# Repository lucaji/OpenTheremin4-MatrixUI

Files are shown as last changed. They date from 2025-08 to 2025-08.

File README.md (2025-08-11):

# OpenTheremin4+ Pitch Detection — Proof of Concept

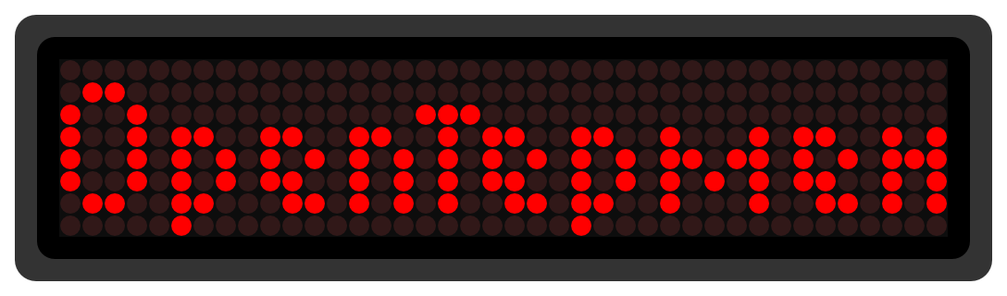
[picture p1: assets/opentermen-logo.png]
OpenTheremin Logo


> A modification and proof-of-concept project for the OpenTheremin V4 instrument, adding an LED matrix display for precise pitch and note indication.

## Quick Start

**What you need:**
- OpenTheremin V4.x board (assembled)
- Arduino UNO board
- HT1635A-based LED matrix board with 5× 8×8 modules
- Dupont wires (for serial TX/RX and I2C)
- PlatformIO installed in VS Code

**Wiring overview:**
1. **OpenTheremin → Arduino UNO**  
   - TX ↔ RX (cross-connect)  
   - GND ↔ GND  
   - On V4.0: solder RX to U10 pin 2 (CH340G)  
   - On V4.5: use pads J3 for both TX and RX
2. **Arduino UNO → HT1635A display board**  
   - I²C (SDA/SCL) + 5V + GND

**To run:**
1. Clone this repository
2. In PlatformIO:
   - Open the `display_firmware` project → select UNO COM port → Upload
   - Open the `opentheremin_mod_firmware` project → select Theremin COM port → Upload
3. Power both boards via USB (or a shared supply)  
4. The LED display will now show the current pitch in real time.

Please refer to the included block diagram below.

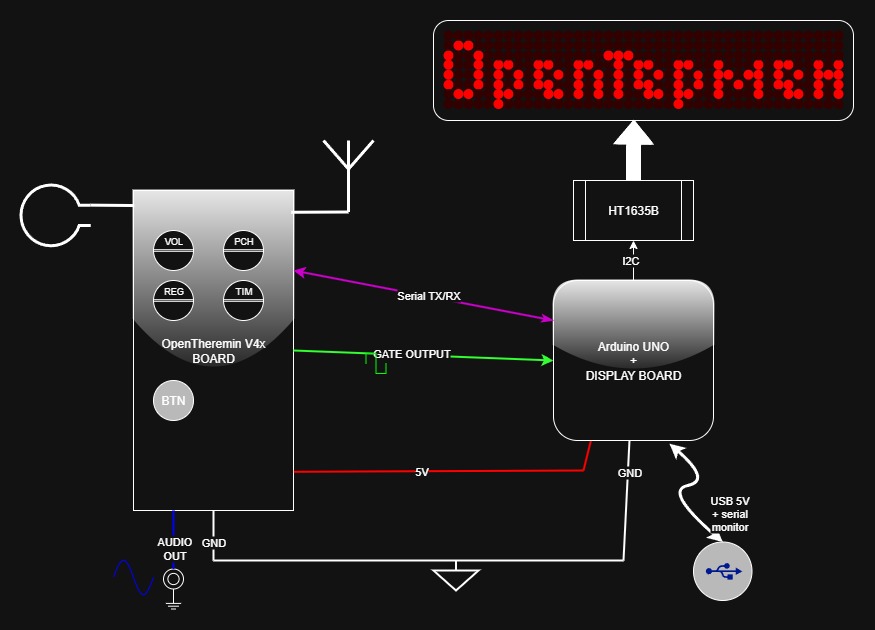
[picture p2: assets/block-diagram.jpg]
Block Diagram


- Both boards communicate via **cross-connected serial ports** (TX↔RX).
- **OpenTheremin V4.0:** TX pad available, RX requires soldering to U10 pin 2 (CH340G).  
- **OpenTheremin V4.5:** Both TX and RX available at solder pads J3.

## Menu & UI Functionality

The user interface is minimal, operated via the **single capacitive touch button** on the OpenTheremin board.

> The menu system cycles through modes and options with **short taps** and confirms selections with **long presses**.

**Main features:**

1. **Calibration**
   - After the first long press, the display will show `CAL?` and with a second long-press you will initiate the calibration procedure on the Theremin.
   When confirming the calibration, the color LEDs will blink briefly signalling to stand in front of the theremin at a comfortable distance and with your hands **away** from the antennas.
   After the calibration is finished, a brief `CALOK` message will put you back into performance mode, otherwise a `CALER` will offer you another attempt.

1. **Layout Selection**  
   - `NUM` **Numeric deviation**: Shows note + octave + cent deviation numerically  
   - `BAR` **Bar graph**: Visual representation of pitch drift from the target note  
   - `PNO` **Piano keyboard**: Highlights current note position on an octave graphic

2. **Concert A Reference**  
   - Preset options: `440 Hz` `445 Hz` `430 Hz` and `432 Hz`
   - Long-press to confirm and store selection

3. **Notation System** (future expansion)  
   - Current: English sharp notation (C, C#, D...)  
   - Planned: Flats, Solfège, and German notation

**Navigation Logic:**
- **Short tap** → Next menu item or value  
- **Long press** → Confirm selection / return to main display  
- In **main tuner view mode**, short taps cycle between `MUTED` and `PLAY!` to control the audio output directly.

---

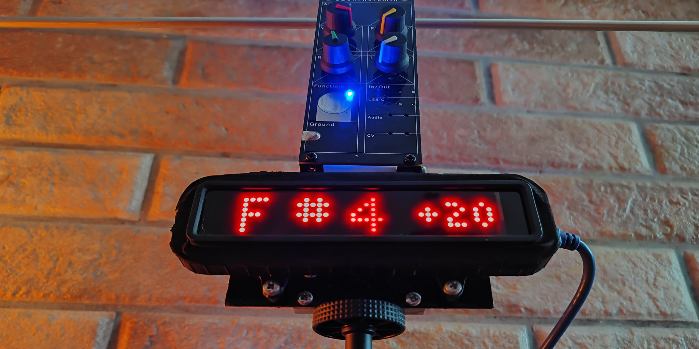
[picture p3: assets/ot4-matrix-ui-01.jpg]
LED Matrix UI


**OpenTheremin with LED matrix display for real-time pitch indication using an HT1635A driver and five 8×8 LED modules.**

## Overview

This project is a **proof-of-concept (POC)** for two main reasons:

1. **Non-optimal display hardware**  
   The LED matrix display board used here was a scrap leftover with less-than-ideal wiring (row/column swapping, reversed bit order).  
   Although a schematic is provided, a redesigned PCB would simplify addressing and improve performance.

2. **Original MCU limitations**  
   The ATmega328p on the OpenTheremin V4 is already at full capacity running the DDS generator and near real-time digital heterodyne system.  
   A second Arduino UNO is therefore required for pitch detection and display driving via the HT1635A.

Communication between the two boards is handled exclusively via the serial port, avoiding any additional load on the main Theremin processor and ensuring glitch-free performance.

## Pitch Indication

The detection system displays:

- **Pitch note** (C, D, E… with sharps/flats)  
- **Octave number**  
- **Deviation in cents** from equal temperament

The display firmware supports **three layouts**:

1. **Numeric deviation**

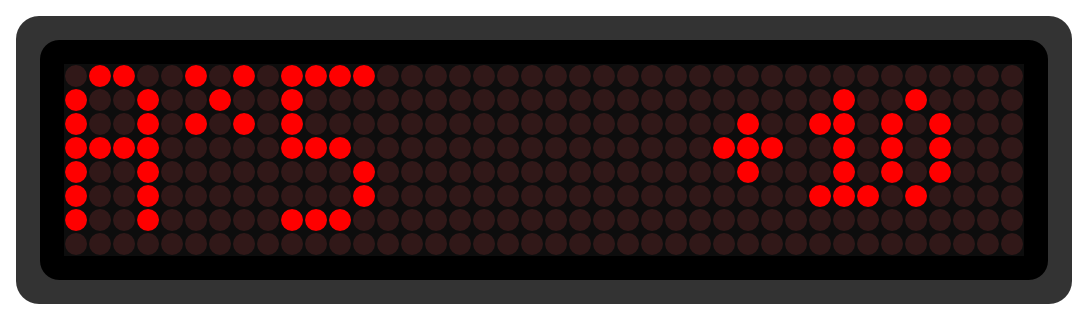
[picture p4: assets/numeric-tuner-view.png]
Numeric Tuner View


2. **Bar graph**

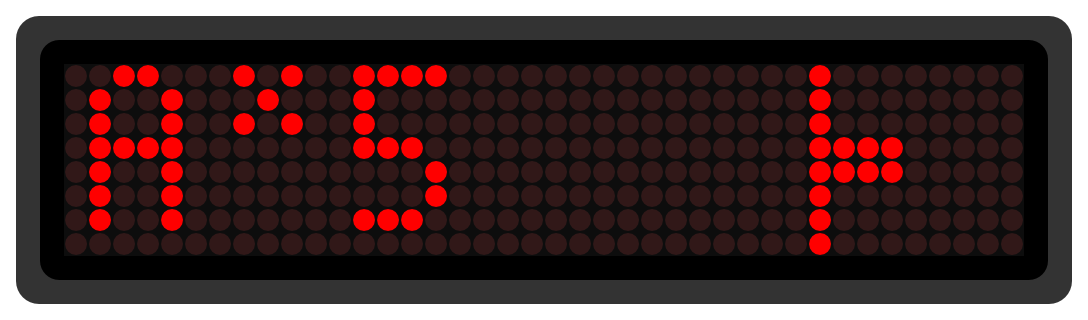
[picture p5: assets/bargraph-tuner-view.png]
Bar-graph Tuner View


3. **Piano keyboard**

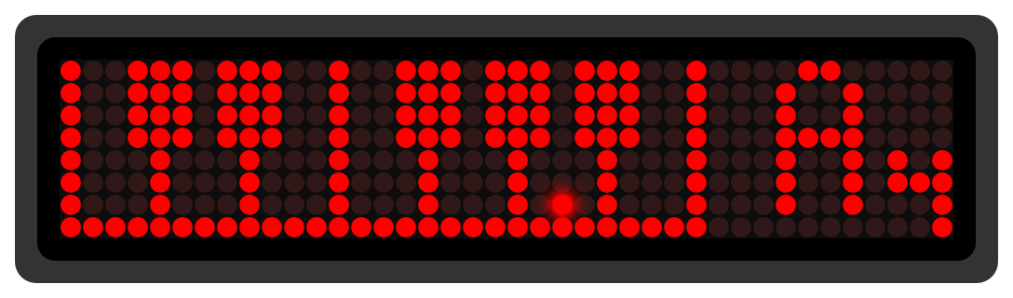
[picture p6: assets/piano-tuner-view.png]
Piano Tuner View


Because of the limited matrix resolution, each layout is a trade-off between visual appeal and precision.

The firmware allows selection of **Concert A tuning** (440 Hz, 432 Hz, etc.) and basic configuration using a **single touch button**.

---

### HT1635A Display Driver

- Controls five 8×8 LED matrices
- Displays standard note names with accidentals
- Shows cent deviation in a smaller font
- Aids Theremin learning by providing visual pitch feedback without the need for another tuned reference instrument (unless you have perfect pitch).

---

### Modded Theremin Firmware

The modified OpenTheremin V4 firmware enables the **GATE output** (ring contact of the audio jack) to emit a square wave pulse at the DDS output frequency.  
This signal is:

- Measured by the secondary Arduino UNO  
- Independent of the volume antenna position  
- Active even when the Theremin is muted

## Hardware Requirements

- **OpenTheremin V4.x** (assembled)  
- **Arduino UNO** as display controller  
- HT1635A-based LED matrix board (five 8×8 modules)  
- I²C connection between UNO and display

Using a second MCU is the simplest way to handle the display without interfering with the Theremin's strict timing requirements or consuming its limited program space.

---

### Display Board Notes

The provided schematic (KiCad v9) reflects a **non-ideal wiring** where row and column lines are swapped and interlaced between display modules.

The HT1635’s RAM is divided into 4-bit nibbles within 40 bytes, requiring careful addressing. Refer to the attached datasheet file for more information.

## Development Environment

This project uses **PlatformIO** for a better workflow than Arduino IDE.  
[Install PlatformIO for VS Code](https://platformio.org/install/ide?install=vscode).

The repo contains **two separate firmware projects**:

1. Modified OpenTheremin firmware  
2. Display board firmware

---

### Serial Port Selection

When uploading:

- Select the correct COM port in each project’s `platformio.ini` (`upload_port = COMx`)
- The OpenTheremin board usually appears as **USB-SERIAL CH340**  
- The Arduino UNO appears as **Arduino UNO**

Keeping both boards connected via USB allows simultaneous UART logging during development.

## Roadmap

- Redesign HT1635 PCB for logical row/column mapping
- Add variable-width font support (currently fixed 6×5)
- Implement additional pitch notation systems:  
   - English sharp/flat  
   - Solfège (Do/Re/Mi) sharp/flat  
   - German sharp/flat

## About the Theremin
The Theremin, invented by Leon Theremin in 1920, is played without physical contact:
One hand controls pitch, the other volume, by moving in proximity to two antennas.

The startup logo in this project merges “Open” with Lev Sergeevič Termen’s surname in Cyrillic (Термен) to fit perfectly on the 8×8×5 matrix display.

## Credits

- Urs Gaudenz (gaudi.ch) — OpenTheremin boards and project founder

- All contributors to the OpenTheremin project

- draw.io Desktop — used for the block diagram

## Revision History

- August 2025 — Initial release by Luca Cipressi [(lucaji.github.io)](http://lucaji.github.io)

## License

Display firmware is licensed under GNU GPL v3.

(c) 2025 Luca Cipressi [(lucaji.github.io)](http://lucaji.github.io)

The original Theremin firmware retains its respective copyrights.

See the full license text in the repository.

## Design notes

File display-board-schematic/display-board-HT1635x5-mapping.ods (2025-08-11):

 | data byte |  |  |  |  |  |  |  |  |  | data byte |  |  |  |  |  |  |  |  |  | data byte |  |  |  |  |  |  |  |  |  | data byte |  |  |  |  |  |  |  |  |  | data byte |  |  |  |  |  |  |  |  |  | data byte
 | 7 | 6 | 5 | 4 | 3 | 2 | 1 | 0 |  |  | 7 | 6 | 5 | 4 | 3 | 2 | 1 | 0 |  |  | 7 | 6 | 5 | 4 | 3 | 2 | 1 | 0 |  |  | 7 | 6 | 5 | 4 | 3 | 2 | 1 | 0 |  |  | 7 | 6 | 5 | 4 | 3 | 2 | 1 | 0 |  |  | 7 | 6 | 5 | 4 | 3 | 2 | 1 | 0
Row # |  |  |  |  |  |  |  |  | ADDR | Row# |  |  |  |  |  |  |  |  | ADDR | Row# |  |  |  |  |  |  |  |  | ADDR | Row# |  |  |  |  |  |  |  |  | ADDR | Row# |  |  |  |  |  |  |  |  | ADDR | Row#
0x00 |  |  |  |  |  |  |  |  | 0x00 | 0x08 |  |  |  |  |  |  |  |  | 0x10 | 0x10 |  |  |  |  |  |  |  |  | 0x20 | 0x18 |  |  |  |  |  |  |  |  | 0x30 | 0x20 |  |  |  |  |  |  |  |  | 0x40 | 0x28 | NC | NC | NC | NC | NC | NC | NC | NC
0x01 |  |  |  |  |  |  |  |  | 0x02 | 0x09 |  |  |  |  |  |  |  |  | 0x12 | 0x11 |  |  |  |  |  |  |  |  | 0x22 | 0x19 |  |  |  |  |  |  |  |  | 0x32 | 0x21 |  |  |  |  |  |  |  |  | 0x42 | 0x29 | NC | NC | NC | NC | NC | NC | NC | NC
0x02 |  |  |  |  |  |  |  |  | 0x04 | 0x0A |  |  |  |  |  |  |  |  | 0x14 | 0x12 |  |  |  |  |  |  |  |  | 0x24 | 0x1A |  |  |  |  |  |  |  |  | 0x34 | 0x22 |  |  |  |  |  |  |  |  | 0x44 | 0x2A | NC | NC | NC | NC | NC | NC | NC | NC
0x03 |  |  |  |  |  |  |  |  | 0x06 | 0x0B |  |  |  |  |  |  |  |  | 0x16 | 0x13 |  |  |  |  |  |  |  |  | 0x26 | 0x1B |  |  |  |  |  |  |  |  | 0x36 | 0x23 |  |  |  |  |  |  |  |  | 0x46 | 0x2B | NC | NC | NC | NC | NC | NC | NC | NC
0x04 |  |  |  |  |  |  |  |  | 0x08 | 0x0C |  |  |  |  |  |  |  |  | 0x18 | 0x14 |  |  |  |  |  |  |  |  | 0x28 | 0x1C |  |  |  |  |  |  |  |  | 0x38 | 0x24 |  |  |  |  |  |  |  |  | 0x48
0x05 |  |  |  |  |  |  |  |  | 0x0A | 0x0D |  |  |  |  |  |  |  |  | 0x1A | 0x15 |  |  |  |  |  |  |  |  | 0x2A | 0x1D |  |  |  |  |  |  |  |  | 0x3A | 0x25 |  |  |  |  |  |  |  |  | 0x4A
0x06 |  |  |  |  |  |  |  |  | 0x0C | 0x0E |  |  |  |  |  |  |  |  | 0x1C | 0x16 |  |  |  |  |  |  |  |  | 0x2C | 0x1E |  |  |  |  |  |  |  |  | 0x3C | 0x26 |  |  |  |  |  |  |  |  | 0x4C
0x07 |  |  |  |  |  |  |  |  | 0x0E | 0x0F |  |  |  |  |  |  |  |  | 0x1E | 0x17 |  |  |  |  |  |  |  |  | 0x2E | 0x1F |  |  |  |  |  |  |  |  | 0x3E | 0x27 |  |  |  |  |  |  |  |  | 0x4E
 | MSB |  |  |  | LSB |  |  |  |  |  | MSB |  |  |  | LSB |  |  |  |  |  | MSB |  |  |  | LSB |  |  |  |  |  | MSB |  |  |  | LSB |  |  |  |  |  | MSB |  |  |  | LSB |  |  |  |  |  | MSB |  |  |  | LSB
 |  | C |  |  |  | D |  |  |  |  |  | E |  |  |  | F |  |  |  |  |  | G |  |  |  | A |  |  |  |  |  | B
drift col: | 0 | 1 | 2 | 3 | 4 | 5 | 6 | 7 |  |  | 8 | 9 | 10 | 11 | 12 | 13 | 14 | 15 |  |  | 16 | 17 | 18 | 19 | 20 | 21 | 22 | 23 |  |  | 24 | 25 | 26 | 27 | 28
 |  |  |  | C# Db |  |  |  |  |  |  |  |  |  |  |  |  |  |  |  |  |  |  |  | G# Ab
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

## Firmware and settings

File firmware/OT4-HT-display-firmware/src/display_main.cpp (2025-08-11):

/**
 * @file display_main.cpp
 * @brief UI state machine for the display board connected to OpenTheremin over UART.
 *
 * Responsibilities:
 *  - Render tuner views (numeric / bar / keyboard).
 *  - Handle single-button UX via short/long presses forwarded from the Theremin board.
 *  - Drive a small configuration menu (calibration, view mode, Concert A reference).
 *  - Show transient feedback for Register (octave) and Timbre (wavetable) changes.
 */
#include "display_main.h"
#include "../../build_options.h"
#include "HT1635.h"
#include "freq.h"
#include "../../eeprom.h"


// ==== Configuration & constants =================================================

/** EEPROM addresses (byte indices). */
static constexpr uint16_t EEPROM_TUNER_VIEW_MODE_ADDRESS = 0x00;
static constexpr uint16_t EEPROM_CONCERT_REF_A_ADDRESS   = 0x01;

/** UI timing (ms). */
static constexpr uint32_t UI_UPDATE_DELAY_MS = 100;
static constexpr uint32_t UI_TEMPORARY_PARAMETER_DISPLAY_MS = 1800;

/** Concert A bounds (Hz) for validation. */
static constexpr float CONCERT_A_MIN = 300.0f;
static constexpr float CONCERT_A_MAX = 600.0f;
static constexpr float CONCERT_A_DEFAULT = 440.0f;

/** Minimum frequency to consider “valid” for note rendering. */
static constexpr float MIN_VALID_FREQ = 10.0f;

// ==== Types =====================================================================

/**
 * @brief UI "page" / status machine for the display.
 */
typedef enum : uint8_t {
    tuner_view = 0,                 /**< Main tuner page. */

    // Menu items (cycled by short presses, confirmed by long press)
    menu_item_cal_enter,
    menu_item_pitch_display_mode_numeric,
    menu_item_pitch_display_mode_bar,
    menu_item_pitch_display_mode_keyboard,
    menu_item_concert_a_440,
    menu_item_concert_a_445,
    menu_item_concert_a_430,
    menu_item_concert_a_432,

    // Temporary feedback display (auto-exit)
    parameter_change_view_temporary_enter,
    parameter_change_view_temporary_wait,

} theremin_status_display_t;

/**
 * @brief What kind of temporary parameter feedback is being shown.
 */
typedef enum : uint8_t {
    none = 0,
    octave,     /**< Register change feedback. */
    timbre,     /**< Waveform change feedback. */
    status_msg, /**< Short textual status like PLAY!/MUTED/etc. */
    menu_txt    /**< Menu text; persists until user action. */
} display_status_parameter_t;

// ==== Globals (module-local) =====================================================

static HT1635 ht_display;

static theremin_state_t _theremin_state = muted;
static theremin_status_display_t _display_status = tuner_view;
static display_status_parameter_t _parameter_display_status = none;

static uint8_t _parameter_value = 0;
static float _concert_reference_a = CONCERT_A_DEFAULT;

// ==== Accessors =================================================================

theremin_state_t get_theremin_state() { return _theremin_state; }


/** Clear screen and return to the main tuner view. */
void restore_tuner_view() {
    _display_status = tuner_view;
    ht_display.update_display();
}


void display_ui_init() {
    ht_display.display_startup_logo();
    ht_display.update_display();
}

/**
 * @brief Show a short message and (optionally) mark it as a temporary parameter display.
 * @param kind One of @ref display_status_parameter_t.
 * @param txt  Null-terminated 5-char string for the 5-char area.
 */
static void display_status_msg(display_status_parameter_t kind, const char* txt) {
    _parameter_display_status = kind;
    // For menu text we keep the current page; for others we enter temporary view.
    if (kind != menu_txt) {
        _display_status = parameter_change_view_temporary_enter;
    }
    ht_display.print_string5(txt);
}

/** Draw menu page by enum. */
void display_menu(theremin_status_display_t status) {
    _display_status = status;
    HT1635::tuner_view_mode_t tuner_view_mode = ht_display.get_tuner_view_mode();
    switch (status) {
        case menu_item_cal_enter: display_status_msg(menu_txt, "CAL? "); break;
        
        case menu_item_pitch_display_mode_numeric:
            if (tuner_view_mode == HT1635::tuner_view_mode_t::numeric) {
                display_status_msg(menu_txt, "NUM <");
            } else {
                display_status_msg(menu_txt, "NUM? ");
            }
            break;
        case menu_item_pitch_display_mode_bar:
            if (tuner_view_mode == HT1635::tuner_view_mode_t::bar_graph) {
                display_status_msg(menu_txt, "BAR <");
            } else {
                display_status_msg(menu_txt, "BAR? ");
            }
            break;
        case menu_item_pitch_display_mode_keyboard:
            if (tuner_view_mode == HT1635::tuner_view_mode_t::piano_view) {
                display_status_msg(menu_txt, "PNO <");
            } else {
                display_status_msg(menu_txt, "PNO? ");
            }
            break;
        
        case menu_item_concert_a_440:
            if (fabsf(_concert_reference_a - 440.0f) < 0.01f) {
                display_status_msg(menu_txt, "A440<");
            } else {
                display_status_msg(menu_txt, "A440?");
            }
            break;
        case menu_item_concert_a_445:
            if (fabsf(_concert_reference_a - 445.0f) < 0.01f) {
                display_status_msg(menu_txt, "A445<");
            } else {
                display_status_msg(menu_txt, "A445?");
            }
            break;
        case menu_item_concert_a_430:
            if (fabsf(_concert_reference_a - 430.0f) < 0.01f) {
                display_status_msg(menu_txt, "A430<");
            } else {
                display_status_msg(menu_txt, "A430?");
            }
            break;
        case menu_item_concert_a_432:
            if (fabsf(_concert_reference_a - 432.0f) < 0.01f) {
                display_status_msg(menu_txt, "A432<");
            } else {
                display_status_msg(menu_txt, "A432?");
            }
            break;

        default: 
        break;
    }
}

/**
 * @brief Handle a user action forwarded from the Theremin (short/long press).
 * Short press: step or toggle; Long press: confirm/apply for the current menu item.
 * @param shortPress true for short press, false for long press.
 */
void handle_user_action(bool shortPress) {
    HT1635::tuner_view_mode_t tuner_view_mode = ht_display.get_tuner_view_mode();
    bool shall_restore_tuner_view = false;
    switch (_display_status) {
        case tuner_view:
            if (shortPress) {
                if (_theremin_state == muted) {
                    Serial.write(STATE_CMD_UNMUTE);
                } else if (_theremin_state == playing) {
                    Serial.write(STATE_CMD_MUTE);
                }
            } else {
                display_menu(menu_item_cal_enter);
            }
        break;

        case menu_item_cal_enter:
            if (shortPress) {
                display_menu(menu_item_pitch_display_mode_numeric);
            } else {
                Serial.write(STATE_CMD_CALIBRATION);
            }
            break;

        case menu_item_pitch_display_mode_numeric:
            if (shortPress) {
                display_menu(menu_item_pitch_display_mode_bar);
            } else {
                tuner_view_mode = ht_display.set_tuner_view_mode(HT1635::tuner_view_mode_t::numeric);
                EEPROM.put(EEPROM_TUNER_VIEW_MODE_ADDRESS, tuner_view_mode);
                shall_restore_tuner_view = true;
            }
            break;

        case menu_item_pitch_display_mode_bar:
            if (shortPress) {
                display_menu(menu_item_pitch_display_mode_keyboard);
            } else {
                tuner_view_mode = ht_display.set_tuner_view_mode(HT1635::tuner_view_mode_t::bar_graph);
                EEPROM.put(EEPROM_TUNER_VIEW_MODE_ADDRESS, tuner_view_mode);
                shall_restore_tuner_view = true;
            }
            break;

        case menu_item_pitch_display_mode_keyboard:
            if (shortPress) {
                display_menu(menu_item_concert_a_440);
            } else {
                tuner_view_mode = ht_display.set_tuner_view_mode(HT1635::tuner_view_mode_t::piano_view);
                EEPROM.put(EEPROM_TUNER_VIEW_MODE_ADDRESS, tuner_view_mode);
                shall_restore_tuner_view = true;
            }
            break;

        case menu_item_concert_a_440:
            if (shortPress) {
                display_menu(menu_item_concert_a_445);
            } else {
                _concert_reference_a = 440.0f;
                EEPROM.put(EEPROM_CONCERT_REF_A_ADDRESS, _concert_reference_a); 
                shall_restore_tuner_view = true;
            }
            break;

        case menu_item_concert_a_445:
            if (shortPress) {
                display_menu(menu_item_concert_a_430);
            } else {
                _concert_reference_a = 445.0f;
                EEPROM.put(EEPROM_CONCERT_REF_A_ADDRESS, _concert_reference_a); 
                shall_restore_tuner_view = true;
            }
            break;

        case menu_item_concert_a_430:
            if (shortPress) {
                display_menu(menu_item_concert_a_432);
            } else {
                _concert_reference_a = 430.0f;
                EEPROM.put(EEPROM_CONCERT_REF_A_ADDRESS, _concert_reference_a); 
                shall_restore_tuner_view = true;
            }
            break;

        case menu_item_concert_a_432:
            if (shortPress) {
                shall_restore_tuner_view = true;
            } else {
                _concert_reference_a = 432.0f;
                EEPROM.put(EEPROM_CONCERT_REF_A_ADDRESS, _concert_reference_a); 
                shall_restore_tuner_view = true;
            }
            break;

        default: break;
    }
    if (shall_restore_tuner_view) {
        restore_tuner_view();
    }
}


/**
 * @brief Read persistent settings from EEPROM and validate.
 */
static void settings_read() {
    // View mode
    int8_t tvm = 0;
    EEPROM.get(EEPROM_TUNER_VIEW_MODE_ADDRESS, tvm);
    if (tvm < 0 || tvm >= HT1635::tuner_view_mode_t::tuner_view_mode_t_last) {
        tvm = HT1635::tuner_view_mode_t::piano_view;
    }
    HT1635::tuner_view_mode_t tuner_view_mode = static_cast<HT1635::tuner_view_mode_t>(tvm);
    ht_display.set_tuner_view_mode(tuner_view_mode);

    float ref_a = 0.0f;
    EEPROM.get(EEPROM_CONCERT_REF_A_ADDRESS, ref_a);
    if (ref_a < CONCERT_A_MIN || ref_a > CONCERT_A_MAX) {
        ref_a = CONCERT_A_DEFAULT;
    }
    _concert_reference_a = ref_a;
}

/**
 * @brief Initialize the HT1635 display and show startup screen.
 */
void setup() {
    Serial.begin(SERIAL_SPEED);
    settings_read();
    ht_display.begin();
    display_ui_init();
    freq_init();
    DEBUG_PRINTLN(F("Display UI ready."));
    _display_status = tuner_view;
}

// ==== Arduino lifecycle ==========================================================

void loop() {
    static unsigned long tuner_view_update_old_tick = 0;
    static unsigned long parameter_view_update_old_tick = 0;

    float raw = freq_read();
    unsigned long t = millis();
    
    // ---- UART protocol from Theremin ------------------------------------------
    if (Serial.available()) {
        uint8_t b = Serial.read();
        switch (b) {
            case STATE_CMD_MUTE:
                _theremin_state = muted;
                display_status_msg(status_msg, "MUTED");
                break;

            case STATE_CMD_UNMUTE:
                _theremin_state = playing;
                display_status_msg(status_msg, "PLAY!");
                break;

            case STATE_CMD_CALIBRATION:
                _theremin_state = calibrating;
                display_status_msg(status_msg, "-CAL-");
                ht_display.set_blink_mode(HT1635::blink_setting_t::BLINK_1Hz);
                break;

            case STATE_CMD_CALIBRATION_SUCCESS:
                _theremin_state = playing;
                ht_display.set_blink_mode(HT1635::blink_setting_t::BLINK_OFF);
                display_status_msg(status_msg, "CALOK");
                break;

            case STATE_CMD_CALIBRATION_ERROR:
                _theremin_state = muted;
                ht_display.set_blink_mode(HT1635::blink_setting_t::BLINK_OFF);
                display_status_msg(status_msg, "CALER");
                _display_status = menu_item_cal_enter;
                break;

            case STATE_CMD_BUTTON_SHORT_PRESS:
                handle_user_action(true);
                break;

            case STATE_CMD_BUTTON_LONG_PRESS:
                handle_user_action(false);
                break;

            default:
                // Parameter ranges: Register (octave) and Timbre (wavetable index).
                if (b >= STATE_CMD_REGISTER_LOW && b <= STATE_CMD_REGISTER_HIGH) {
                    _display_status = parameter_change_view_temporary_enter;
                    _parameter_display_status = octave;
                    _parameter_value = b;
                } else if (b >= STATE_CMD_WAVEFORM_BASE && b <= (STATE_CMD_WAVEFORM_BASE + 0x9)) {
                    _display_status = parameter_change_view_temporary_enter;
                    _parameter_display_status = timbre;
                    _parameter_value = b - STATE_CMD_WAVEFORM_BASE;
                } else {
                    // Unrecognized; ignore or DEBUG_PRINT(b);
                    //DEBUG_PRINT(b); // echo
                }
                break;
        }
    }

    switch (_display_status) {
        case tuner_view:
            if (t - tuner_view_update_old_tick > UI_UPDATE_DELAY_MS) {
                tuner_view_update_old_tick = t;
                ht_display.render_pitch_and_drift(raw, _concert_reference_a, MIN_VALID_FREQ);
            }
            break;

        case parameter_change_view_temporary_enter:
            parameter_view_update_old_tick = t;
            switch (_parameter_display_status) {
                case octave: {
                    char txt[6] = "OCT+1";
                    if (_parameter_value == STATE_CMD_REGISTER_LOW) {
                        txt[3] = '-';
                    } else if (_parameter_value == STATE_CMD_REGISTER_MID) {
                        txt[4] = '0';
                    } 
                    ht_display.print_string5(txt);
                } break;

                case timbre: {
                    char txt[6] = "WAV  ";
                    txt[4] = char((_parameter_value % 10) + '0');
                    ht_display.print_string5(txt);
                } break;

                default: break;
            }
            _display_status = parameter_change_view_temporary_wait;
            break;

        case parameter_change_view_temporary_wait:
            if (_parameter_display_status == menu_txt || _theremin_state == calibrating) {
                // menu items stays until user exits menu.
                // calibration stays until success or failure.
            } else if (t - parameter_view_update_old_tick > UI_TEMPORARY_PARAMETER_DISPLAY_MS) {
                _display_status = tuner_view;
                _parameter_display_status = none;
                restore_tuner_view();
            }

            break;

        default: break;
    }
        

        


}

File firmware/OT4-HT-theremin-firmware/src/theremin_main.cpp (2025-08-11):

#include <Arduino.h>
#include "../../build_options.h"
#include "dac.h"
#include "ihandlers.h"
#include "timer.h"
#include "eeprom.h"
#include "hw.h"
#include "ui.h"
#include "calibration.h"
#include "cv.h"

void setup() {
    Serial.begin(SERIAL_SPEED);

    pinMode(BUTTON_PIN, INPUT_PULLUP);
    pinMode(LED_BLUE_PIN, OUTPUT);
    pinMode(LED_RED_PIN, OUTPUT);
    pinMode(GATE_PIN, OUTPUT);

    ui_initialize();

    calibration_read();
    ihInitialiseTimer();
    ihInitialiseInterrupts();

    DEBUG_PRINTLN("Hello, Theremin world!");
}

void loop() {
    int32_t pitch_v = 0;    // averaged pitch counter value
    int32_t pitch_l = 0;    // stored pitch counter value
    
    int32_t vol_v = 0;      // averaged volume counter value
    int32_t vol_l = 0;      // stored volume counter value

    int32_t clampedVol;     // clamped volume amplitude
    int32_t clampedPitch;   // clamped pitch for phase accumulator

mloop: // Main loop avoiding the GCC "optimization"

    if (pitchValueAvailable) {
        // --- Smooth pitch value (simple IIR low-pass filter) ---
        pitch_v = pitch_l + ((pitch - pitch_l) >> 2); // (low-pass) exponential moving average (EMA) approximation 75% previous, 25% new
        pitch_l = pitch_v;
        /*
        ((int32_t)pitchPotValue << 1)   // for half sensitivity
        ((int32_t)pitchPotValue << 3)   // for double sensitivity
        ((int32_t)pitchPotValue - 512) << 2   // center the pot at zero offset
        */
        #if PITCH_FIELD_MODE == PITCH_FIELD_MODE_SYMMETRICAL
            int32_t virtualPitch = pitch_v + (((int32_t)pitchPotValue - 512) << 2);  // apply offset
            clampedPitch = abs(pitchCalibrationBase - virtualPitch);
        #else
            clampedPitch = (pitchCalibrationBase - pitch_v) + 2048 - (pitchPotValue << 2);
        #endif
        if (clampedPitch < 0) { 
            // Lower clamp
            clampedPitch = 0;
        } else if (clampedPitch > 16383) {
            // Upper clamp
            // 16383 = 2^14 - 1
            // This value is shifted right by registerValue, or the selected octave (or pitch register).
            // If registerValue == 0, no shift: vPointerIncrement = 16383 (maximum playback speed).
            // vPointerIncrement is directly used to advance the phase pointer per sample.
            // Larger values -> faster wavetable traversal -> higher pitch.
            // Using a limit of 16383 ensures that:
            // - The shifted result stays within a reasonable frequency range, avoiding unplayably high tones.
            // - avoid wraparound in the phase accumulator or numeric overflow in later math.
            // - It fits well with common 10.6 fixed-point formats.
            clampedPitch = 16383;
        }
        setWavetableSampleAdvance((uint16_t)clampedPitch >> registerValue);
        
        #if CV_OUTPUT_MODE != CV_OUTPUT_MODE_OFF
            if (clampedPitch != pitch_p) { 
                // output new pitch CV value only if pitch value changed (saves runtime resources)
                pitch_p = clampedPitch;
                #if CV_OUTPUT_MODE == CV_OUTPUT_MODE_LOG
                    log_freq = log2U16((uint16_t)clampedPitch);
                    if (log_freq >= 37104) {
                        // 37104 = log2U16(512) + 48*4096/819
                        pitchCV = (int16_t)((819 * (log_freq - 37104)) >> 12);
                        pitchCV >>= registerValue - 1;
                    } else {
                        pitchCV = 0;
                    }
                #elif CV_OUTPUT_MODE == CV_OUTPUT_MODE_LINEAR
                    // 819Hz/V for Korg & Yamaha
                    pitchCV = clampedPitch >> 2 >> (registerValue - 1);
                #endif
                pitchCVAvailable = true;
            }
        #endif
        pitchValueAvailable = false;  // consume the flag
    }

    if (volumeValueAvailable) {
        // Average and clamp volume values
        vol = max(vol, 5000);
        vol_v = vol_l + ((vol - vol_l) >> 2); // (low-pass) exponential moving average (EMA) approximation
        vol_l = vol_v;

        if (audio_is_enabled()) {
            vol_v = DAC_12BIT_MAX - (volCalibrationBase - vol_v) / 2 + (volumePotValue << 2) - 1024;
        } else {
            vol_v = 0;
        }

        // Limit and set volume value
        vol_v = min(vol_v, DAC_12BIT_MAX);
        vol_v = max(vol_v, 0);
        clampedVol = vol_v >> 4;
        // Give vScaledVolume a pseudo-exponential characteristic:
        vScaledVolume = clampedVol * (clampedVol + 2);

        // if enabled output CV Volume ONLY (GATE output is being used to be measured by the display board)
        #if CV_OUTPUT_MODE == CV_OUTPUT_MODE_LOG || CV_OUTPUT_MODE == CV_OUTPUT_MODE_LINEAR
            // Most synthesizers "exponentiate" the volume CV themselves, thus send the "raw" volume for CV:
            volCV = vol_v;
            volumeCVAvailable = true;
        #endif
        volumeValueAvailable = false;
    }
    
    ui_do_loop();

    goto mloop; // End of main loop
}

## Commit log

2025-08-11 first tested firmware release.
    [Electronics-OT-HD.kicad_pcb, Electronics-OT-HD.kicad_sch, display-board-HT1635x5-mapping.ods]
2025-08-11 activate red LED (muted state) at power-cycle.
2025-08-11 potentiometers are now correctly read at startup too
    [ui.cpp]
